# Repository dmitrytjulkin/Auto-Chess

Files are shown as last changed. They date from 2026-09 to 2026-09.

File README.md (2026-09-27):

# Автоматические шахматы
Данный репозиторий содержит инструкцию по созданию "автоматических шахмат". Здесь хранятся чертежи установки, функциональные схемы, перечень необходимых компонентов, CAD модели используемых деталей, процесс сборки проекта.

## Описание функционала
Автоматическая доска способна самостоятельно передвигать фигуры. Это открывает следующие возможности: переставлять фигуры дистанционно, управлять ими с помощью бота.

## Команда проекта
- Тюлькин Дмитрий - @dmitrytjulkin
- Бойко Марина - @boyko_marinaa
- Павлов Дмитрий - @lorddmp

## Источники
- https://www.instructables.com/Automated-Chessboard/

## Последние действия
Мы рассмотрели модель доски 1x2 клеток, прикрепили к нижней части два геркона и проверили их работу - взаимодействие с фигурами, в дно которых был вставлен магнит:
Тестирование герконов

Также мы проверили работу шаговых моторов:
Тестирование шаговых моторов

## Последние коммиты
commit 240173
Author: Tyulkin Dmitriy
Date:   Sun Sep 27 23:49:40 2026 +0300

    loaded essential CADs

commit c43c56
Author: Tyulkin Dmitriy
Date:   Sun Sep 27 23:31:54 2026 +0300

    added script for testing stepper motors

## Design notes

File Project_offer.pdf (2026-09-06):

Предложение проекта: Автоматические шахматы.

Менторы: Азамат Георгиевич и Евгений Игоревич.
Команда:
- Тюлькин Дмитрий, Б01-505, @dmitrytjulkin, 79192475219, tiulkin.da@phystech.edu;
- Павлов Дмитрий, Б01-505, @lorddmp;
- Бойко Марина, Б01-505, @boyko_marinaa.

Цель проекта: Сконструировать дистанционно управляемую, автоматизированную шахматную доску, способную самостоятельно передвигать шахматные фигуры.

Описание функционала: Доска обеспечивает игру в двух режимах: “человек против человека”, “человек против компьютера”. Суть проекта раскрывается в режиме “человек против компьютера”: ходы компьютера совершаются автоматически, анализируются программой Stockfish.

Задачи проекта:
1. Создание XY-стола,
2. Реализация “захвата” фигур,
3. Идентификация положения фигур по клеткам,
4. Программная идентификация типа фигуры,
5. Создание скрипта, контролирующего движение фигур,
6. Создание скрипта, связывающего Stockfish и ходы игрока.

Анализ существующих аналогов:
Automated Chessboard:
https://www.instructables.com/Automated-Chessboard/
Основные идеи проекта взяты отсюда.

Эскиз проекта:
Ниже представлен эскиз XY-стола, а также схема-описание, как осуществляется передвижение по плоскости XY:

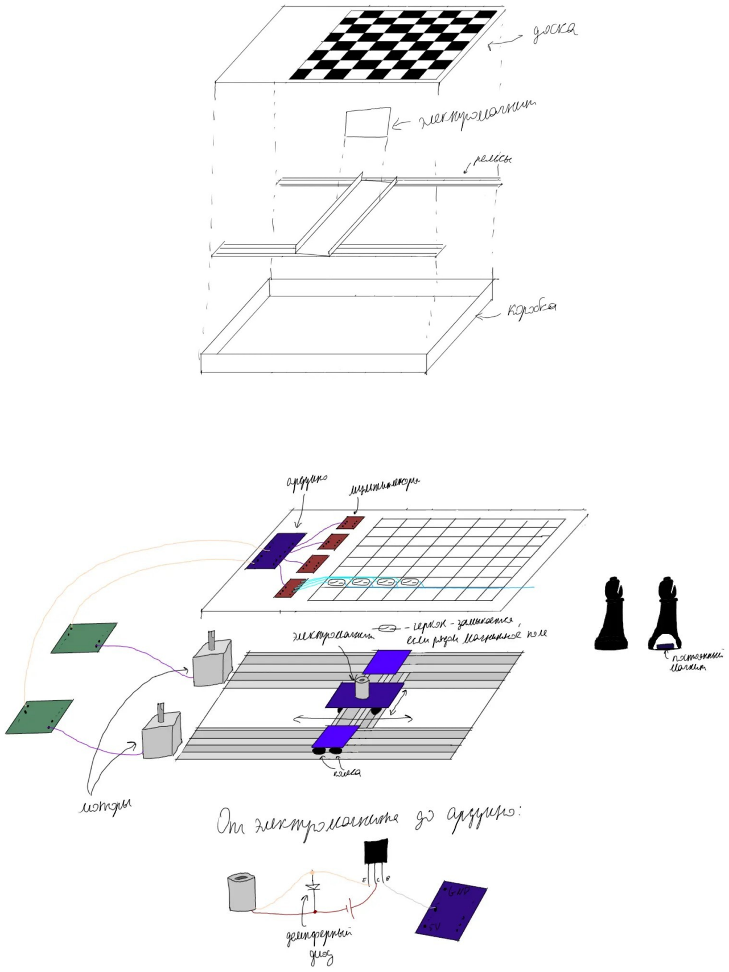
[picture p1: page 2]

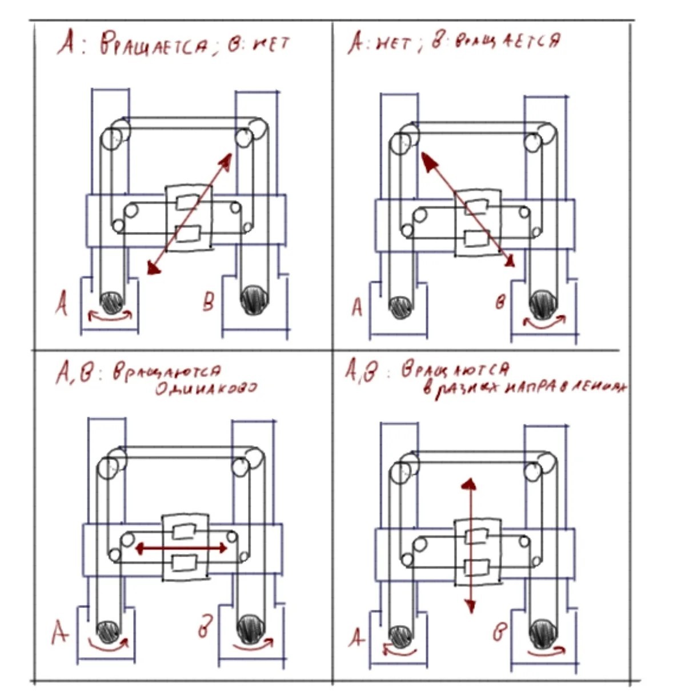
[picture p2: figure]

Элементная база:
- XY стол
Название детали | Кол-во | Где можно купить
V-slot линейный рельс | 4 | https://www.soberizavod.ru/catalog/seriya_20_v_paz_anodirovannyj/profil_konstruktsionnyy_v20kh20_an_serebro/
GT2 шкив 20 зубьев | 2 | https://xn--80aaxidg9j.xn--p1ai/catalog/ shkivy/shkiv-gt2-20-d-otverstiya-8-mm/
GT2 шкив без зубьев | 8 | https://amperkot.ru/products/rolik_gt2_6_mm_bez_zubev/39784389.html?ysclid=mtp3u8x7yq30911657
GT2 ремень 6 мм | 1 | https://www.ozon.ru/product/zubchatyy-remen-gt2-6-mm-pro-2055286285/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
Шаговый мотор Adafruit Nema 17 size 12 v | 2 | https://www.chipdip.ru/product/324-adafruit-accessories-stepper-motor-nema17-12v-8006391701?

| | ysclid=mtp3hdpbwp911082753
Ролик профильный V-образный | 8 | https://zona-3d.ru/catalog/alyuminievyy_profil/roliki_profilnye/rolik_profilnyy_2020_v_obraznyy_625zz_s_kanavkoy
угловой кронштейн 90o | 10 | https://aliexpress.ru/popular/90-corner-bracket
- “Хваталка”
Название детали | Кол-во | Где можно купить
Электромагнит | 1 | https://www.ozon.ru/product/elektromagnit-24v-25h20mm-5kg-578812380/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
Биполярный транзистор | 1 | https://www.chipdip.ru/product/tip120-bipolyarnyy-tranzistor-npn-60v-st-microelectronics-8230269581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 Pv-O05tbqp5zF-AKzLdr6yM64qr6iMc5ditZcjh50d5d2dkYWZocWx5 YWt0dmxr.cb7d62246aa27368011a79fda05914be7f48 2931&yclid=5508717543126204415&ybaip=1
Диод свободного хода | 1 | https://www.chipdip.ru/product/1n5819-diod-shottki-40v-1a-25a-do-41-st-microelectronics-9000442595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 NCxWqrN35scnwF3CWM7oaWtueXBsZHJmeW1sb3 B3ag.e8fe21bc5609c5113e645b494be3c573bf0e2b55 &yclid=17525419175825899519&ybaip=1
- Доска
Название детали | Кол-во | Где можно купить
Герконы 2x14.5 мм | 64 | https://www.ozon.ru/product/5sht-reed-switch-magnetic-control-switch-2-14mm-magnetic-induction-reed-switch-2x14mm-long-2803846366/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

Магниты 8x3 мм | 32 | https://www.ozon.ru/product/magnit-disk-koltso-8x3mm-s-zenkovkoy-podhodit-bolt-vint-m3-10-shtmagnit-disk-1556631557/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
Мультиплексор -CD74HC4067 | 4 | https://www.chipdip.ru/product/bob-09056-switch-ic-development-tools-a-d-mux-sparkfun-8004800004
- Электроника
Название детали | Кол-во | Где можно купить
Ардуино Нано | 1 | Физтех Фабрика
Шаговый драйвер моторы - Pololu - A4988 | 2 | https://www.chipdip.ru/product/drayver-shagovogo-dvigatelya-a4988-s-radiatorom-8004125452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 274
- Другие комплектующие
Название детали | Кол-во | Где можно купить
Эксцентриковая проставка

Разделитель (Spacer)
Подшипники
Прокладка (Shim)
Гайка

Остальные детали будут напечатаны на 3д принтере или обработаны лазерной резкой (например, шахматные фигуры).

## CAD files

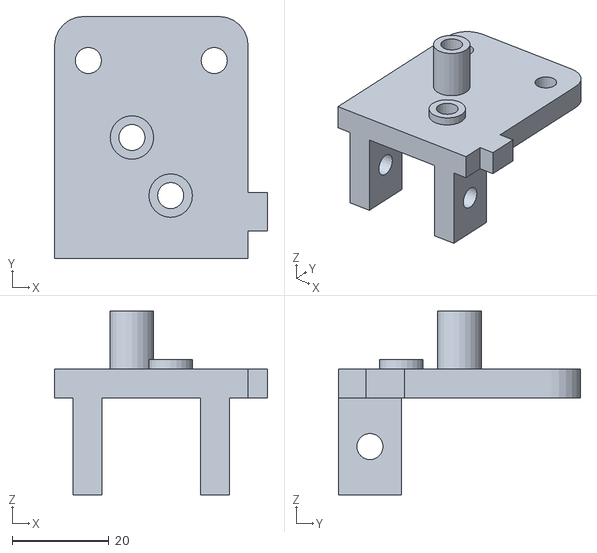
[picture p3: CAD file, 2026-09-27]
CAD_models/Trolley_Support_A.stl
44.0 x 50.0 x 38.0

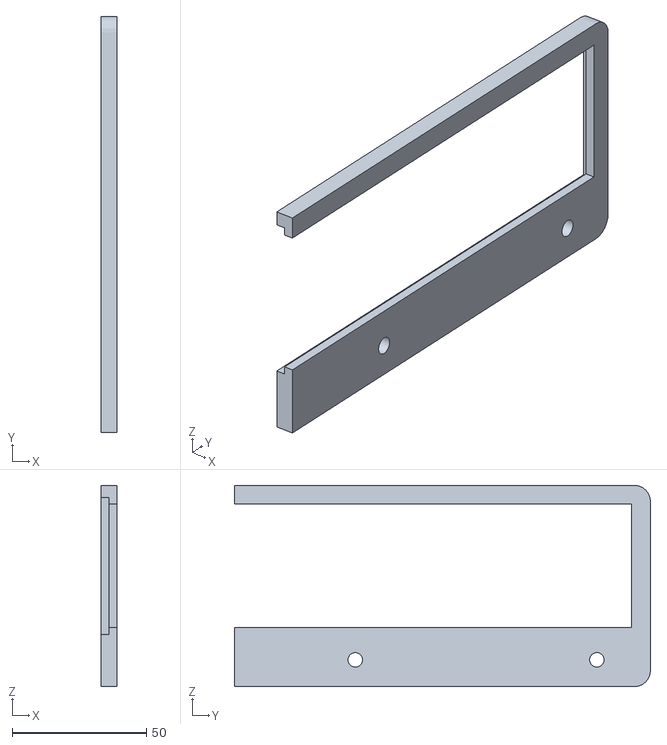
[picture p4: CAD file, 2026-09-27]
CAD_models/Electronic_Support_A.stl
6.00 x 155.0 x 75.0

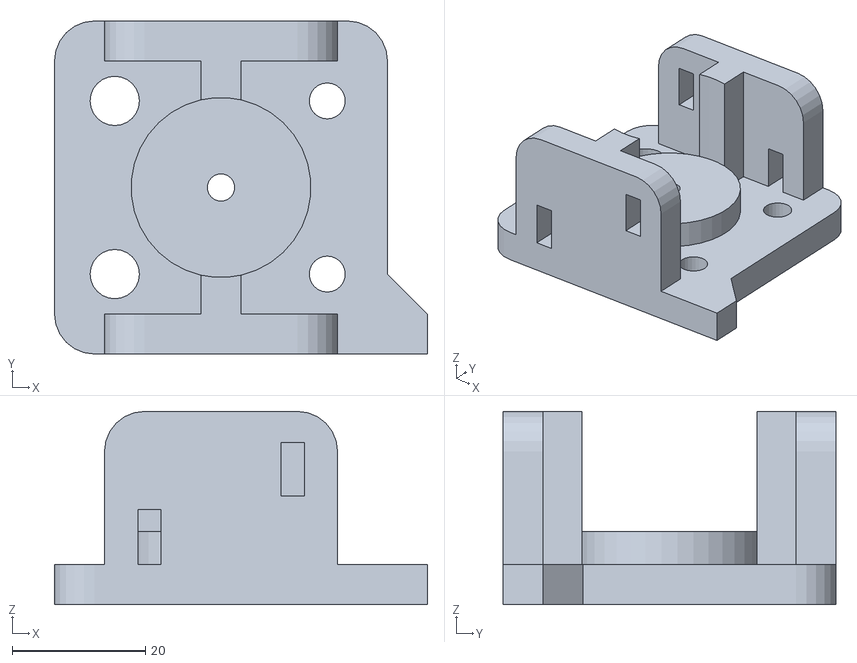
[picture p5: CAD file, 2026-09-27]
CAD_models/Electromagnet_Support.stl
56.0 x 50.0 x 29.0

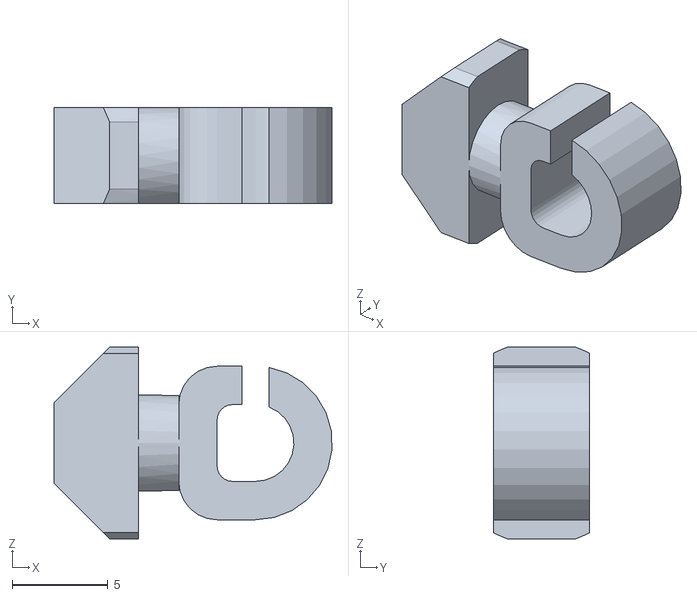
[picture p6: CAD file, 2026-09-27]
CAD_models/Cable_Clip.stl
14.5 x 5.00 x 10.0

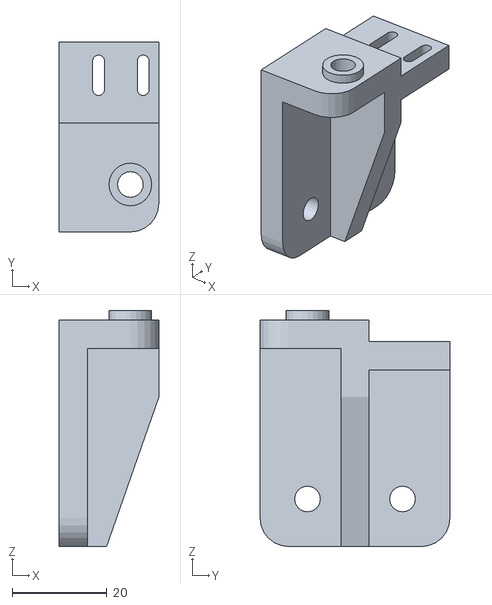
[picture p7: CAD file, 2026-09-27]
CAD_models/Pulley_Support_B.stl
21.0 x 40.0 x 49.7

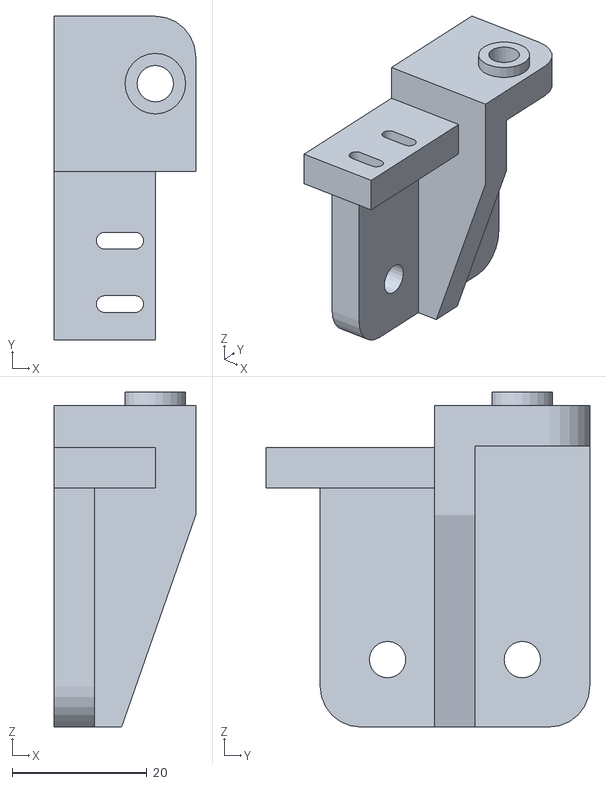
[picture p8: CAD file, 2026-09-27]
CAD_models/Pulley_Support_A.stl
21.0 x 48.0 x 49.7

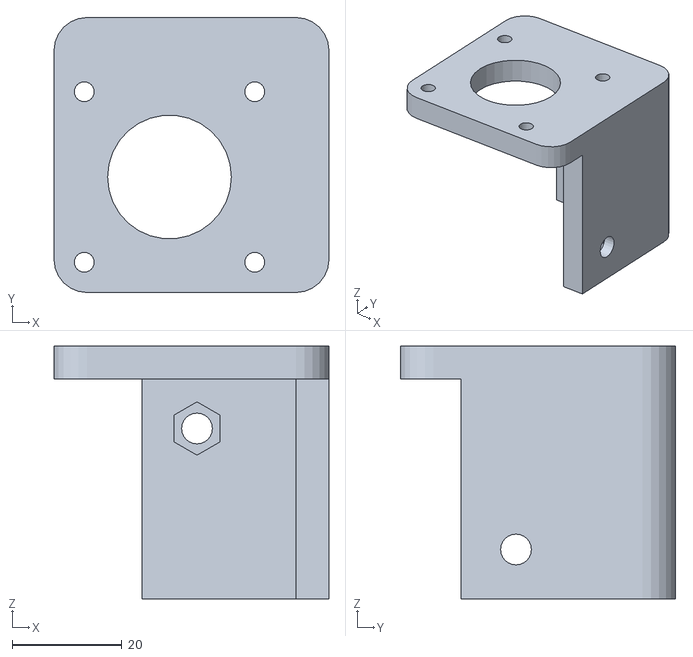
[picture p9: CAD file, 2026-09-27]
CAD_models/Motor_Support_B.stl
50.0 x 50.0 x 46.0

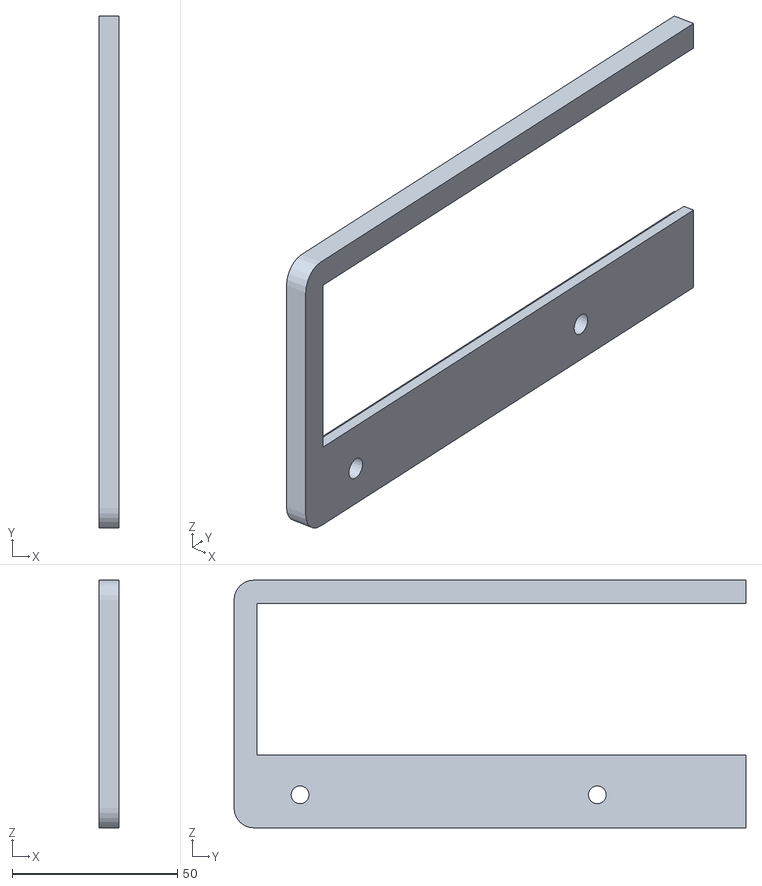
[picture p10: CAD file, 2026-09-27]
CAD_models/Electronic_Support_B.stl
6.00 x 155.0 x 75.0

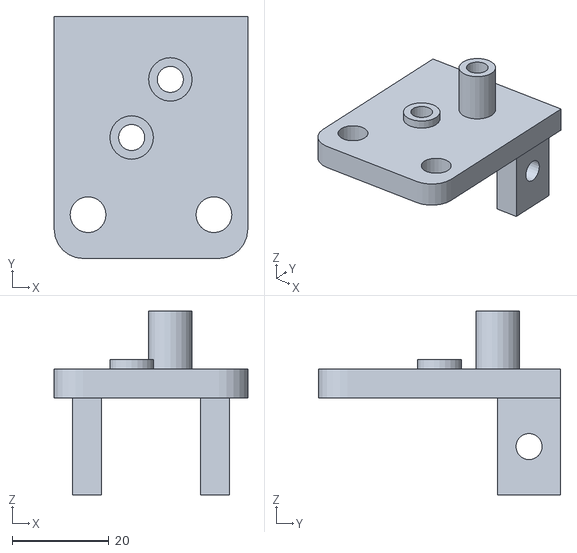
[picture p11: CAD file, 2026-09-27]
CAD_models/Trolley_Support_B.stl
40.0 x 50.0 x 38.0

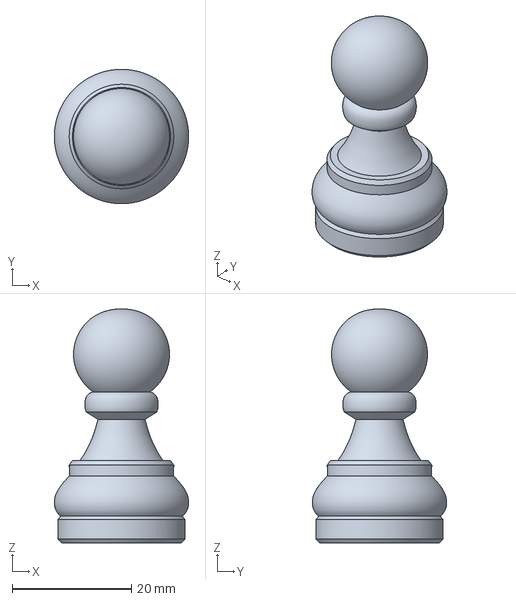
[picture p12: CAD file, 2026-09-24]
CAD_models/chess_pawn.3mf
22.5 x 22.5 x 39.2 mm

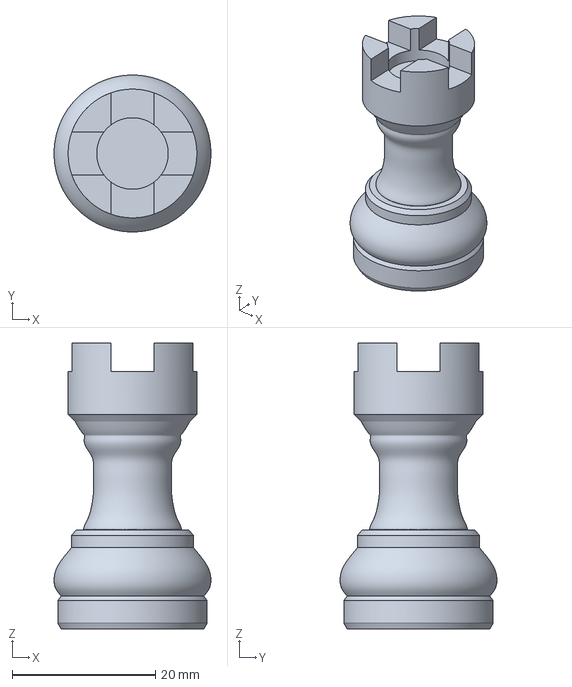
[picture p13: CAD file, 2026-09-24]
CAD_models/chess_rock.3mf
21.9 x 21.9 x 40.0 mm

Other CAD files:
CAD_models/Motor_Support_A.stl

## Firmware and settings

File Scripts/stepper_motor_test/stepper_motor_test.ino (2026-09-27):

#include <GyverStepper.h>
#include <string.h>

#define X_STEP_PIN 54
#define X_DIR_PIN  55
#define X_EN_PIN   38

#define Y_STEP_PIN 60
#define Y_DIR_PIN  61
#define Y_EN_PIN   56

#define STEPS_PER_REV 3200  

GStepper<STEPPER2WIRE> stepperX(STEPS_PER_REV, X_STEP_PIN, X_DIR_PIN);
GStepper<STEPPER2WIRE> stepperY(STEPS_PER_REV, Y_STEP_PIN, Y_DIR_PIN);

void runUntilDone(GStepper<STEPPER2WIRE> &s);

#define RULE_STEPPER(given_cmd, direction, stepper_name,                      \
                    stepper_aim, start_response, final_response)              \
    (strcmp(cmd, given_cmd) == 0) {                                           \
      if (direction == 1) stepper_aim += STEPS_PER_REV;                       \
      else                stepper_aim -= STEPS_PER_REV;                       \
                                                                              \
      Serial.println(start_response);                                         \
                                                                              \
      stepper_name.setTarget(stepper_aim);                                    \
      runUntilDone(stepper_name);                                             \
                                                                              \
      Serial.println(final_response);                                         \
    }

#define RULE_BOTH(given_cmd, direction, start_response, final_response)       \
    (strcmp(cmd, given_cmd) == 0) {                                           \
      if (direction == 1) {x_aim += STEPS_PER_REV; y_aim += STEPS_PER_REV;}   \
      else                {x_aim -= STEPS_PER_REV; y_aim -= STEPS_PER_REV;}   \
                                                                              \
      Serial.println(start_response);                                         \
                                                                              \
      stepperX.setTarget(x_aim);                                              \
      stepperY.setTarget(y_aim);                                              \
                                                                              \
      while (stepperX.tick() | stepperY.tick()) {}                            \
                                                                              \
      Serial.println(final_response);                                         \
    }

void setup() {
  pinMode(X_EN_PIN, OUTPUT);
  digitalWrite(X_EN_PIN, LOW);
  pinMode(Y_EN_PIN, OUTPUT);
  digitalWrite(Y_EN_PIN, LOW);

  Serial.begin(9600);

  stepperX.setMaxSpeed(900);
  stepperX.setAcceleration(500);
  stepperY.setMaxSpeed(900);
  stepperY.setAcceleration(500);

  Serial.println("Ready. CMDS: x_front — X goes clockwise, y_front — Y goes clockwise, \n"
                 "x_back, y_back - cmds for X and Y going anticlockwise\n"
                 "both_front — X and Y goes clockwise, both_back - X and Y goes anticlockwise\n\n");
}

long x_aim = 0;
long y_aim = 0;

void loop() {
  if (Serial.available()) {
    char cmd[32];
    size_t len = Serial.readBytesUntil('\n', cmd, sizeof(cmd) - 1);
    cmd[len] = '\0';

    if RULE_STEPPER("x_front", 1, stepperX, x_aim, "X: goes clockwise", "X: done\n")
    
    else if RULE_STEPPER("y_front", 1, stepperY, y_aim, "Y: goes clockwise", "Y: done\n")

    else if RULE_STEPPER("x_back", -1, stepperX, x_aim, "X: goes anticlockwise", "X: done\n")

    else if RULE_STEPPER("y_back", -1, stepperY, y_aim, "Y: goes anticlockwise", "Y: done\n")

    else if RULE_BOTH("both_front", 1, "X, Y: go clockwise", "X, Y: done")

    else if RULE_BOTH("both_back", -1, "X, Y: go anticlockwise", "X, Y: done")
  }
}

// Крутит мотор, пока он не доедет до цели
void runUntilDone(GStepper<STEPPER2WIRE> &s) {
  while (s.tick()) {}
}

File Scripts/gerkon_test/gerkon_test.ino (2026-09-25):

const int whitereedPin = A3; 
const int blackreedPin = A4;  


void setup() {
  Serial.begin(9600);

  pinMode(whitereedPin, INPUT_PULLUP); // включаем внутренний подтягивающий резистор
  Serial.println("Проверка геркона на A3");

  pinMode(blackreedPin, INPUT_PULLUP); // включаем внутренний подтягивающий резистор
  Serial.println("Проверка геркона на A4");
}

void loop() {
  int state_white = digitalRead(whitereedPin);
  int state_black = digitalRead(blackreedPin);

  int white_square = 0;
  int black_square = 0;

  if (state_white == LOW) {
    white_square = 1;
  }

  if (state_black == LOW)
    black_square = 1;

  for (int i = 0; i < 20; ++i)
    Serial.println("\n");

  Serial.println("_______");
  Serial.println("|     |");
  Serial.print("|  "); Serial.print(white_square); Serial.println("  |");
  Serial.println("|     |");
  Serial.println("_______");
  Serial.println("|     |");
  Serial.print("|  "); Serial.print(black_square); Serial.println("  |");
  Serial.println("|     |");
  Serial.println("_______");

  delay(500);
}


// void setup() {
//   pinMode(13, OUTPUT); // встроенный светодиод на Mega
// }

// void loop() {
//   digitalWrite(13, HIGH); // включить
//   delay(2000);
//   digitalWrite(13, LOW);  // выключить
//   delay(200);
// }

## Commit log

2026-09-24 added CADs of pawn and rock
    [chess_pawn.3mf, chess_rock.3mf]
2026-09-25 added arduino script to test reed switches
2026-09-25 added gif of testing reed switches to readme
2026-09-27 added script for testing stepper motors
2026-09-27 loaded essential CADs
    [Cable_Clip.stl, Electromagnet_Support.stl, Electronic_Support_A.stl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]
2026-09-27 added gif of testing stepper motors
2026-10-08 added files for laser
2026-10-15 added video of testing mux and photo of 3 reed switchess on the board
